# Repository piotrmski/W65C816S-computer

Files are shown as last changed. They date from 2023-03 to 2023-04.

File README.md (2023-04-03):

# W65C816S single-board computer

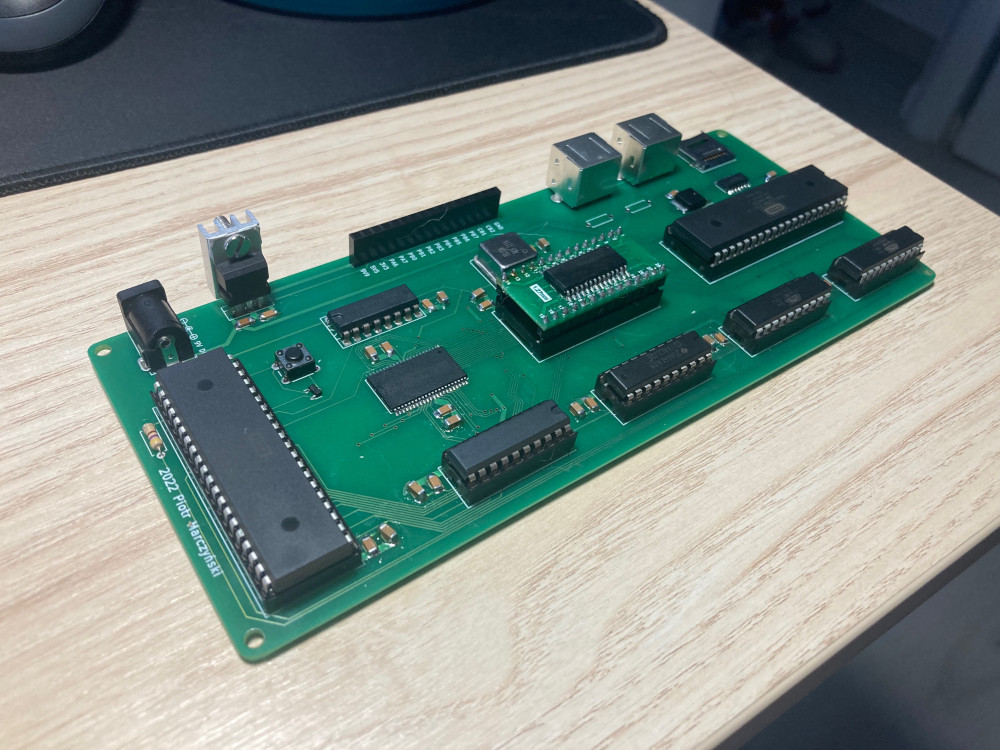
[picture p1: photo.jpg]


The following repository documents my novice attempt at designing a microprocessor single-board computer. I had fun putting this design together, however without any prior experience it's left with many flaws which should be addressed if anyone would want to implement it again.

It's a KiCad project, however a single-page PDF of the schematic and gerber files are included, so KiCad is not required to preview it.

### Specs

- W65C816S processor clocked at 10 MHz
- 504 KiB RAM
- 7.75 KiB ROM at half clock speed
- W65C22S peripheral device controller (VIA)
- Dual PS/2 input
- MicroSD input via SPI
- W65C22S's PA6, PA7, PB0-7, CB1, CB2 exposed as general purpose output, intended to drive a character display

### Address space

- 00000-0DFFF - 56 KiB of RAM intended for stack and direct page
- 0E000-0E0FF - I/O (4 least significant bits address VIA, bits 5-7 are unused)
- 0E100-0FFFF - 7.75 KiB of ROM
- 10000-7FFFF - 448 KiB of RAM

### What I think I did right

- It's simple.
- It's compact.
- It's fast.

### Quirks of the design

- In the PCB design many of the components are in DIP packages, my choice of DIP was motivated by the ability to prototype on breadboards.
- In the PCB design capacitors are relatively large to allow hand soldering; resistors are DIP because that's what I had on hand.
- 256 B of ROM (1/32) and 8 KiB of RAM (1/64) are wasted, however I consider it not a big deal.
- Not all SD cards support SPI interface.

### What I did wrong

- The ATF16V8Cs consume unreasonable amounts of energy, glue logic should have been designed with discrete logic gate components.
- Removing and replugging the entire ROM chip to flash it is too fiddly, a programming connector would make programming this device simpler.
- ROM is read only, however it would be simple enough to add a physical switch allowing the processor to write to ROM.

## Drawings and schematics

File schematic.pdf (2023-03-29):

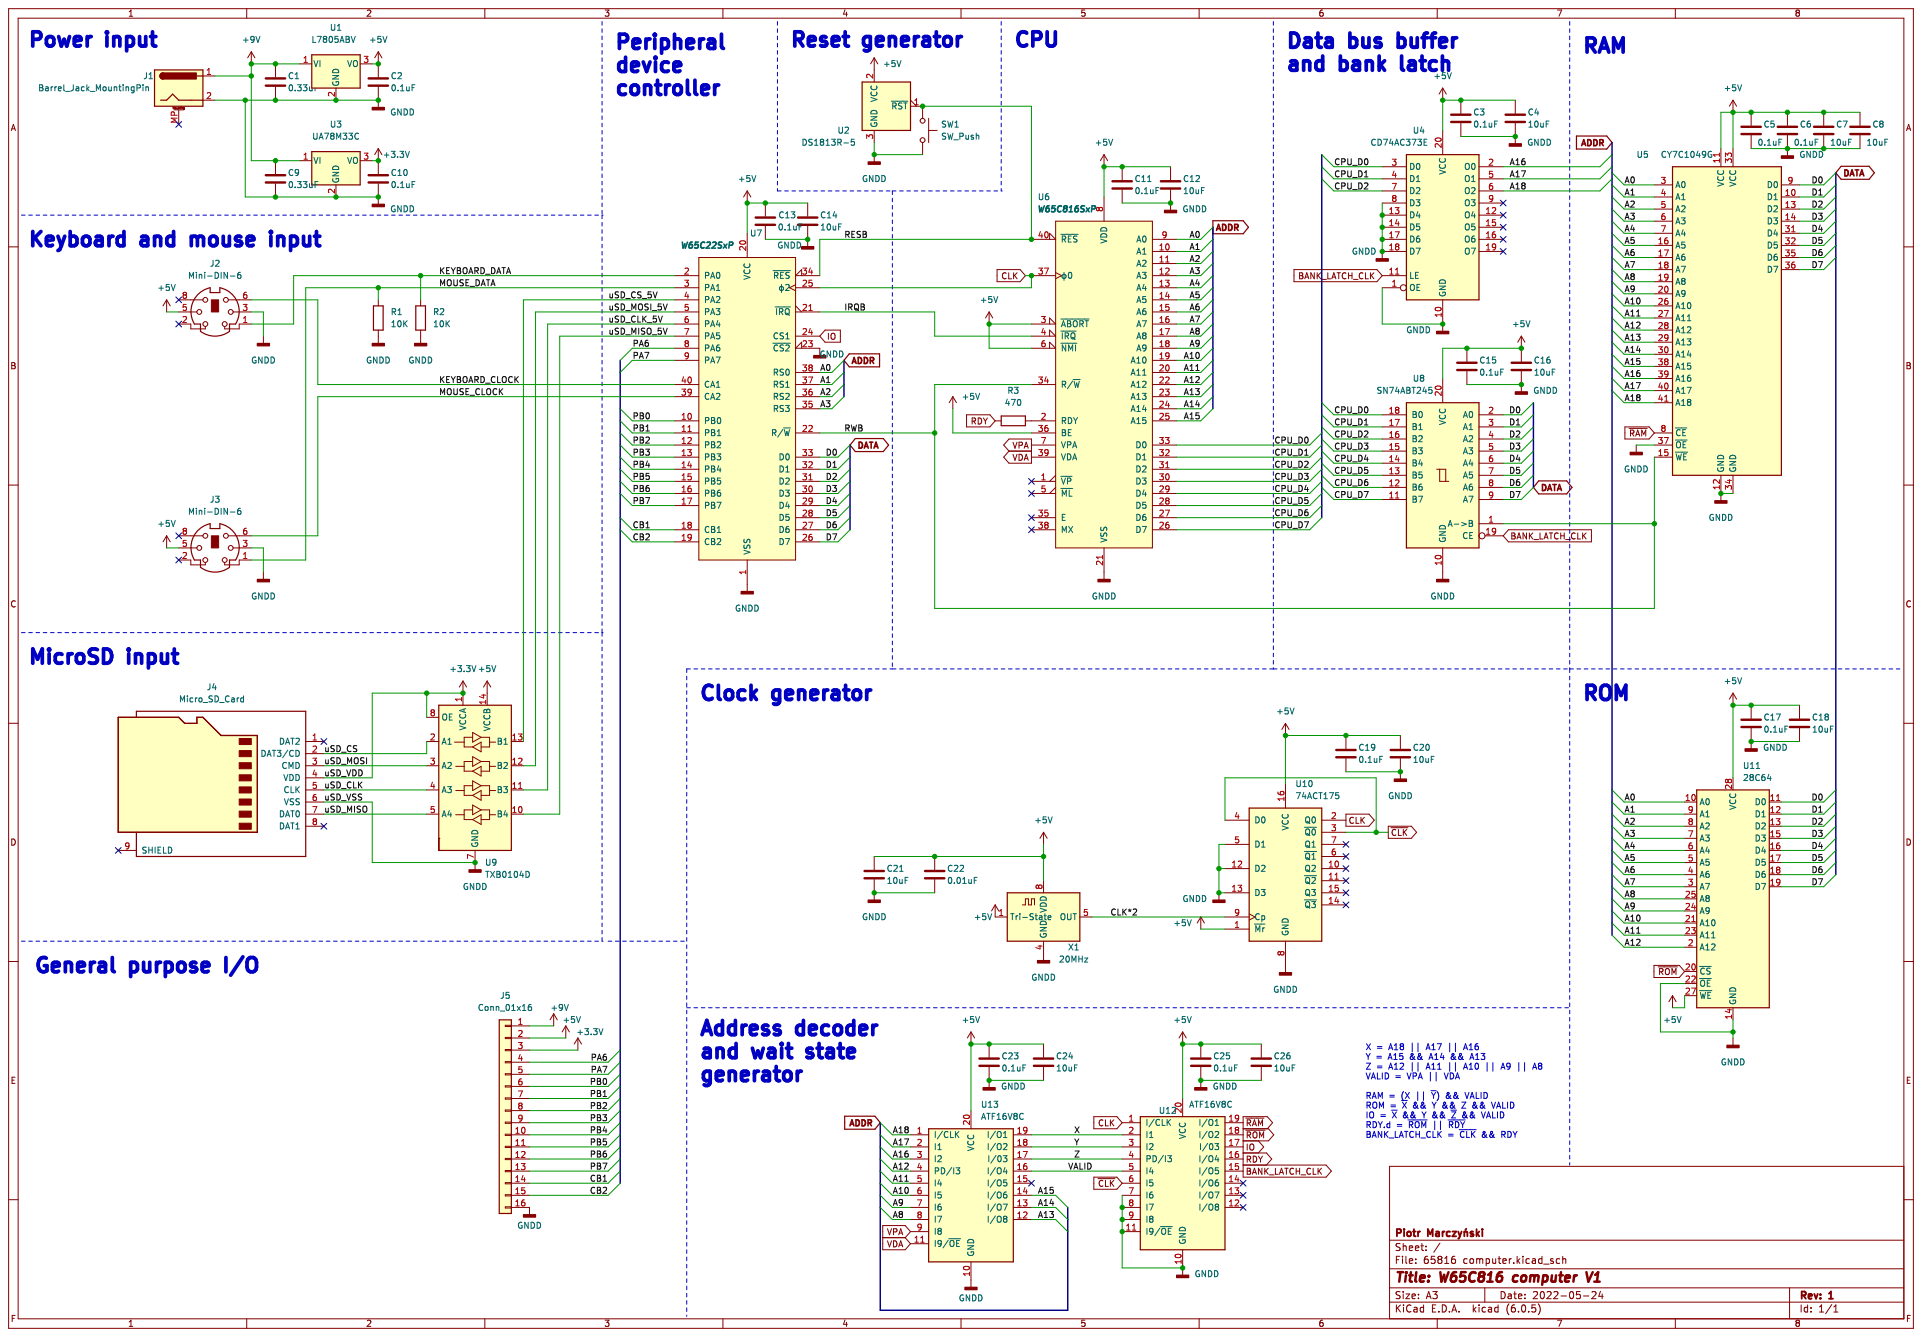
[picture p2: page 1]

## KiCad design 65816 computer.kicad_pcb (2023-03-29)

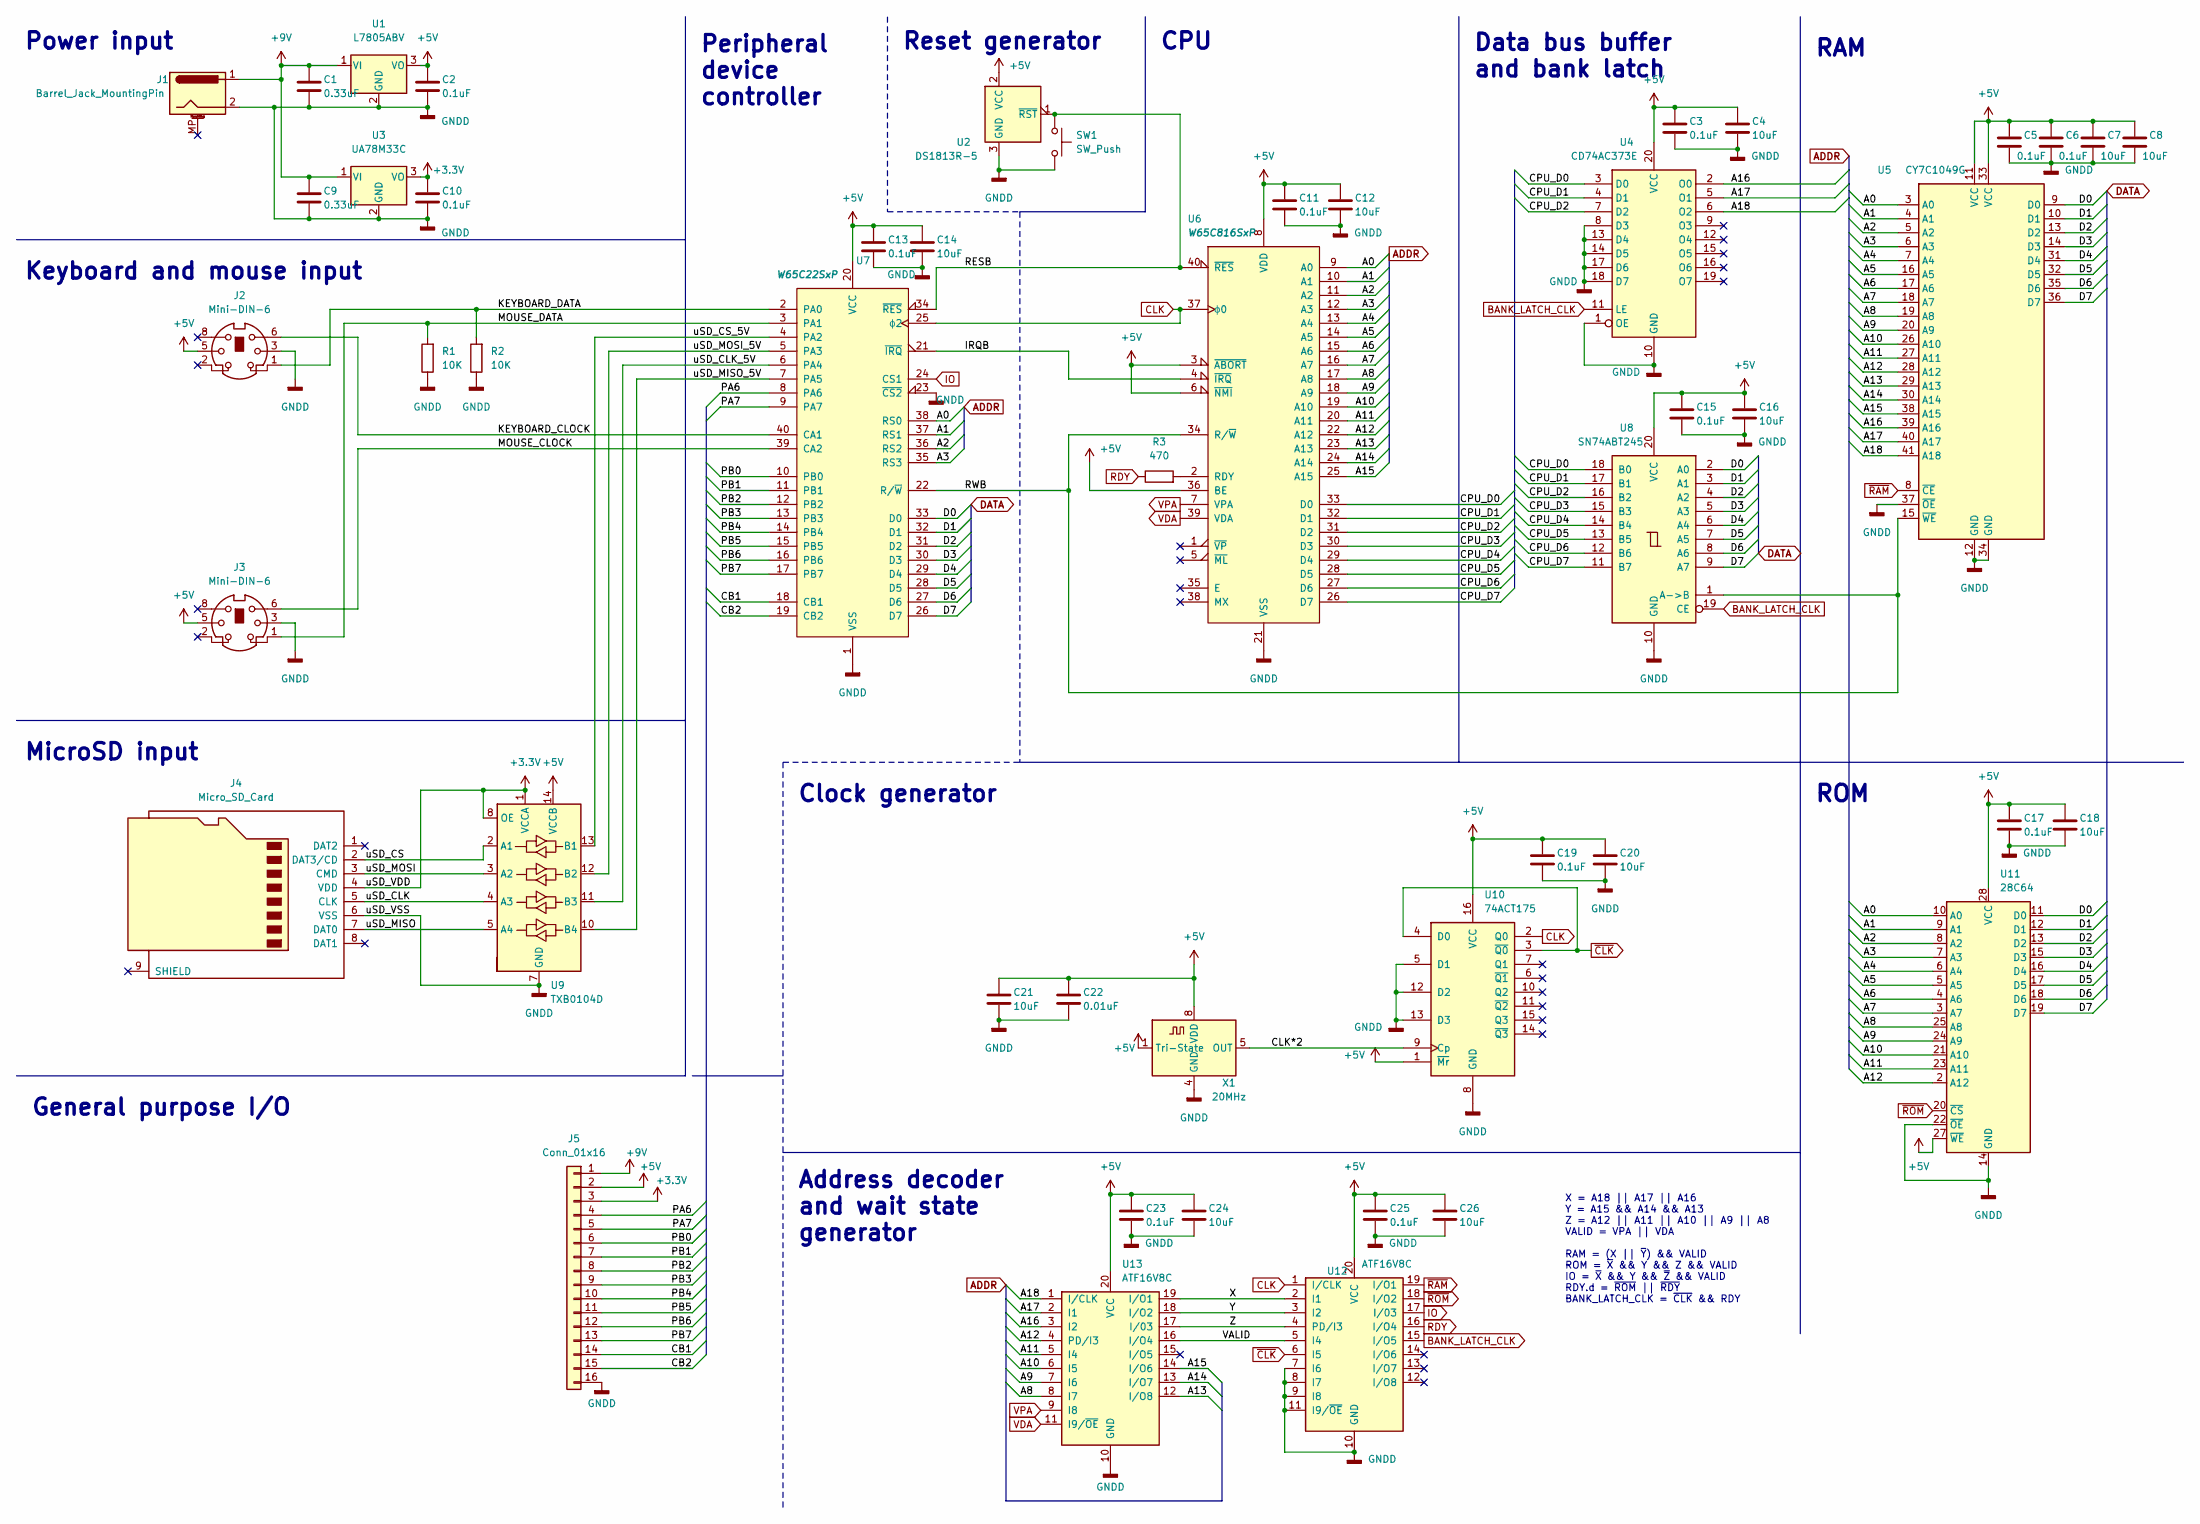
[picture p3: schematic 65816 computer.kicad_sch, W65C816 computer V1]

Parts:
C1, C9: 0.33uF; C_1206_3216Metric_Pad1.33x1.80mm_HandSolder
C2, C3, C5, C6, C10, C11, C13, C15, C17, C19, C23, C25: 0.1uF; C_1206_3216Metric_Pad1.33x1.80mm_HandSolder
C4, C7, C8, C12, C14, C16, C18, C20, C21, C24, C26: 10uF; C_1206_3216Metric_Pad1.33x1.80mm_HandSolder
C22: 0.01uF; C_1206_3216Metric_Pad1.33x1.80mm_HandSolder
J1: Barrel_Jack_MountingPin; BarrelJack_GCT_DCJ200-10-A_Horizontal
J2, J3: Mini-DIN-6; KMDGX6SBS
J4: Micro_SD_Card; microSD_HC_Wuerth_693072010801
J5: Conn_01x16; PinHeader_1x16_P2.54mm_Vertical
R1, R2: 10K; R_Axial_DIN0207_L6.3mm_D2.5mm_P7.62mm_Horizontal
R3: 470; R_Axial_DIN0207_L6.3mm_D2.5mm_P7.62mm_Horizontal
SW1: SW_Push; SW_PUSH_6mm
U1: L7805ABV; TO-220-3_Vertical
U2: DS1813R-5; SOT-23
U3: UA78M33C; TO-252-2
U4: CD74AC373E; DIP-20_W7.62mm_Socket_LongPads
U5: CY7C1049G; TSOP-II-44_10.16x18.41mm_P0.8mm
U6: W65C816SxP; DIP-40_W15.24mm_Socket_LongPads
U7: W65C22SxP; DIP-40_W15.24mm_Socket_LongPads
U8: SN74ABT245; DIP-20_W7.62mm_Socket_LongPads
U9: TXB0104D; SOIC-14_3.9x8.7mm_P1.27mm
U10: 74ACT175; DIP-16_W7.62mm_Socket_LongPads
U11: 28C64; DIP-28_W15.24mm_Socket_LongPads
U12, U13: ATF16V8C; DIP-20_W7.62mm_Socket_LongPads
X1: 20MHz; Oscillator_DIP-8

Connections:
+3V3: C10.1, J4.4 (VDD), J5.3, U3.3 (VO), U9.1 (VCCA), U9.8 (OE)
+5V: C2.1, C3.1, C4.1, C5.1, C6.1, C7.1, C8.1, C11.1, C12.1, C13.1, C14.1, C15.1, C16.1, C17.1, C18.1, C19.1, C20.1, C21.1, C22.1, C23.1, C24.1, C25.1, C26.1, J2.5, J3.5, J5.2, U1.3 (VO), U2.2 (VCC), U4.20 (VCC), U5.11 (VCC), U5.33 (VCC), U6.3 (~ABORT), U6.6 (~NMI), U6.8 (VDD), U6.36 (BE), U7.20 (VCC), U8.20 (VCC), U9.14 (VCCB), U10.1 (~Mr), U10.16 (VCC), U11.27 (~WE), U11.28 (VCC), U12.20 (VCC), U13.20 (VCC), X1.1 (Tri-State), X1.8 (VDD)
+9V: C1.1, C9.1, J1.1, J5.1, U1.1 (VI), U3.1 (VI)
/A0: U5.3 (A0), U6.9 (A0), U7.38 (RS0), U11.10 (A0)
/A1: U5.4 (A1), U6.10 (A1), U7.37 (RS1), U11.9 (A1)
/A2: U5.5 (A2), U6.11 (A2), U7.36 (RS2), U11.8 (A2)
/A3: U5.6 (A3), U6.12 (A3), U7.35 (RS3), U11.7 (A3)
/A4: U5.7 (A4), U6.13 (A4), U11.6 (A4)
/A5: U5.16 (A5), U6.14 (A5), U11.5 (A5)
/A6: U5.17 (A6), U6.15 (A6), U11.4 (A6)
/A7: U5.18 (A7), U6.16 (A7), U11.3 (A7)
/A8: U5.19 (A8), U6.17 (A8), U11.25 (A8), U13.8 (I7)
/A9: U5.20 (A9), U6.18 (A9), U11.24 (A9), U13.7 (I6)
/A10: U5.26 (A10), U6.19 (A10), U11.21 (A10), U13.6 (I5)
/A11: U5.27 (A11), U6.20 (A11), U11.23 (A11), U13.5 (I4)
/A12: U5.28 (A12), U6.22 (A12), U11.2 (A12), U13.4 (PD/I3)
/A13: U5.29 (A13), U6.23 (A13), U13.12 (I/O8)
/A14: U5.30 (A14), U6.24 (A14), U13.13 (I/O7)
/A15: U5.38 (A15), U6.25 (A15), U13.14 (I/O6)
/A16: U4.2 (O0), U5.39 (A16), U13.3 (I2)
/A17: U4.5 (O1), U5.40 (A17), U13.2 (I1)
/A18: U4.6 (O2), U5.41 (A18), U13.1 (I/CLK)
/CB1: J5.14, U7.18 (CB1)
/CB2: J5.15, U7.19 (CB2)
/CLK*2: U10.9 (Cp), X1.5 (OUT)
/CPU_D0: U4.3 (D0), U6.33 (D0), U8.18 (B0)
/CPU_D1: U4.4 (D1), U6.32 (D1), U8.17 (B1)
/CPU_D2: U4.7 (D2), U6.31 (D2), U8.16 (B2)
/CPU_D3: U6.30 (D3), U8.15 (B3)
/CPU_D4: U6.29 (D4), U8.14 (B4)
/CPU_D5: U6.28 (D5), U8.13 (B5)
/CPU_D6: U6.27 (D6), U8.12 (B6)
/CPU_D7: U6.26 (D7), U8.11 (B7)
/D0: U5.9 (D0), U7.33 (D0), U8.2 (A0), U11.11 (D0)
/D1: U5.10 (D1), U7.32 (D1), U8.3 (A1), U11.12 (D1)
/D2: U5.13 (D2), U7.31 (D2), U8.4 (A2), U11.13 (D2)
/D3: U5.14 (D3), U7.30 (D3), U8.5 (A3), U11.15 (D3)
/D4: U5.31 (D4), U7.29 (D4), U8.6 (A4), U11.16 (D4)
/D5: U5.32 (D5), U7.28 (D5), U8.7 (A5), U11.17 (D5)
/D6: U5.35 (D6), U7.27 (D6), U8.8 (A6), U11.18 (D6)
/D7: U5.36 (D7), U7.26 (D7), U8.9 (A7), U11.19 (D7)
/IRQB: U6.4 (~IRQ), U7.21 (~IRQ)
/KEYBOARD_CLOCK: J2.6, U7.40 (CA1)
/KEYBOARD_DATA: J2.1, R2.2, U7.2 (PA0)
/MOUSE_CLOCK: J3.6, U7.39 (CA2)
/MOUSE_DATA: J3.1, R1.2, U7.3 (PA1)
/PA6: J5.4, U7.8 (PA6)
/PA7: J5.5, U7.9 (PA7)
/PB0: J5.6, U7.10 (PB0)
/PB1: J5.7, U7.11 (PB1)
/PB2: J5.8, U7.12 (PB2)
/PB3: J5.9, U7.13 (PB3)
/PB4: J5.10, U7.14 (PB4)
/PB5: J5.11, U7.15 (PB5)
/PB6: J5.12, U7.16 (PB6)
/PB7: J5.13, U7.17 (PB7)
/RESB: SW1.1, U2.1 (~RST), U6.40 (~RES), U7.34 (~RES)
/RWB: U5.15 (~WE), U6.34 (R/~W), U7.22 (R/~W), U8.1 (A->B)
/VALID: U12.5 (I4), U13.16 (I/O4)
/X: U12.2 (I1), U13.19 (I/O1)
/Y: U12.3 (I2), U13.18 (I/O2)
/Z: U12.4 (PD/I3), U13.17 (I/03)
/uSD_CLK: J4.5 (CLK), U9.4 (A3)
/uSD_CLK_5V: U7.6 (PA4), U9.11 (B3)
/uSD_CS: J4.2 (DAT3/CD), U9.2 (A1)
/uSD_CS_5V: U7.4 (PA2), U9.13 (B1)
/uSD_MISO: J4.7 (DAT0), U9.5 (A4)
/uSD_MISO_5V: U7.7 (PA5), U9.10 (B4)
/uSD_MOSI: J4.3 (CMD), U9.3 (A2)
/uSD_MOSI_5V: U7.5 (PA3), U9.12 (B2)
BANK_LATCH_CLK: U4.11 (LE), U8.19 (CE), U12.15 (I/O5)
CLK: U6.37 (ϕ0), U7.25 (ϕ2), U10.2 (Q0), U12.1 (I/CLK)
IO: U7.24 (CS1), U12.17 (I/03)
unnamed: R3.2, U6.2 (RDY)
RDY: R3.1, U12.16 (I/O4)
VDA: U6.39 (VDA), U13.11 (I9/~OE)
VPA: U6.7 (VPA), U13.9 (I8)
~CLK: U10.3 (~Q0), U10.4 (D0), U12.6 (I5)
~RAM: U5.8 (~CE), U12.19 (I/O1)
~ROM: U11.20 (~CS), U12.18 (I/O2)

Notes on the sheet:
ROM
Reset generator
Clock generator
Address decoder and wait state generator
Data bus buffer and bank latch
Power input
General purpose I/O
Keyboard and mouse input
RAM
MicroSD input
CPU
Peripheral device controller
X = A18 || A17 || A16 Y = A15 && A14 && A13 Z = A12 || A11 || A10 || A9 || A8 VALID = VPA || VDA RAM = (X || ~{Y}) && VALID ROM = ~{X} && Y && Z && VALID IO = ~{X} && Y && ~{Z} && VALID RDY.d = ~{ROM} || ~{RDY} BANK_LATCH_CLK = ~{CLK} && RDY

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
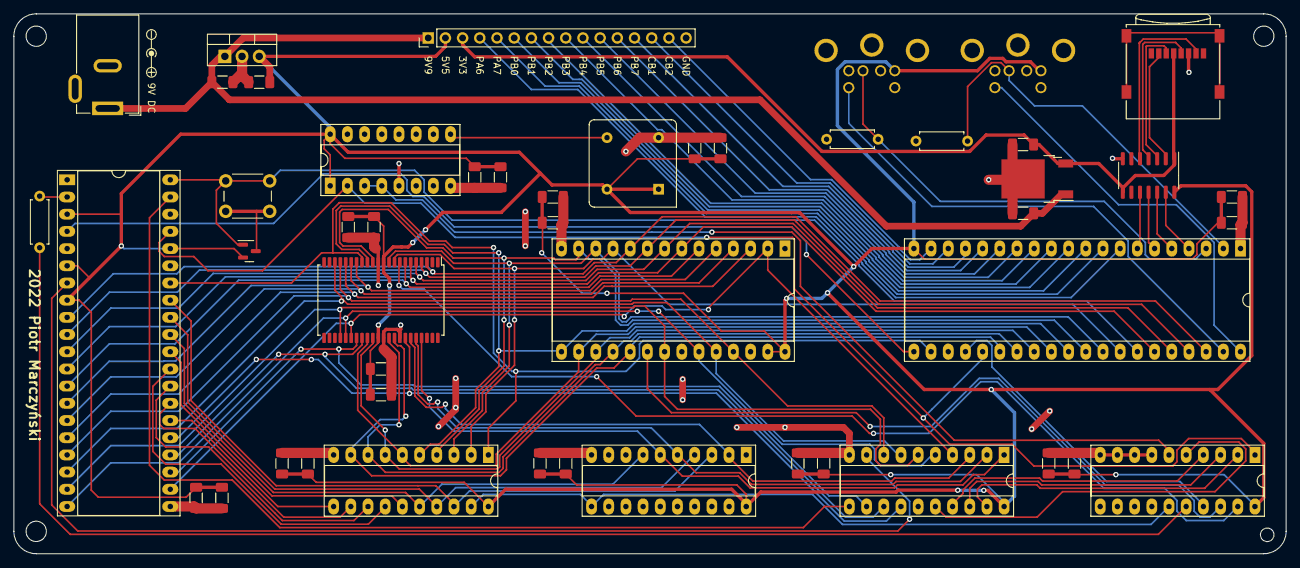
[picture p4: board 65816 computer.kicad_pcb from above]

Board: 2 copper layers, 188.0 x 79.8 mm, 49 parts (0 on the bottom side), 81 nets.
